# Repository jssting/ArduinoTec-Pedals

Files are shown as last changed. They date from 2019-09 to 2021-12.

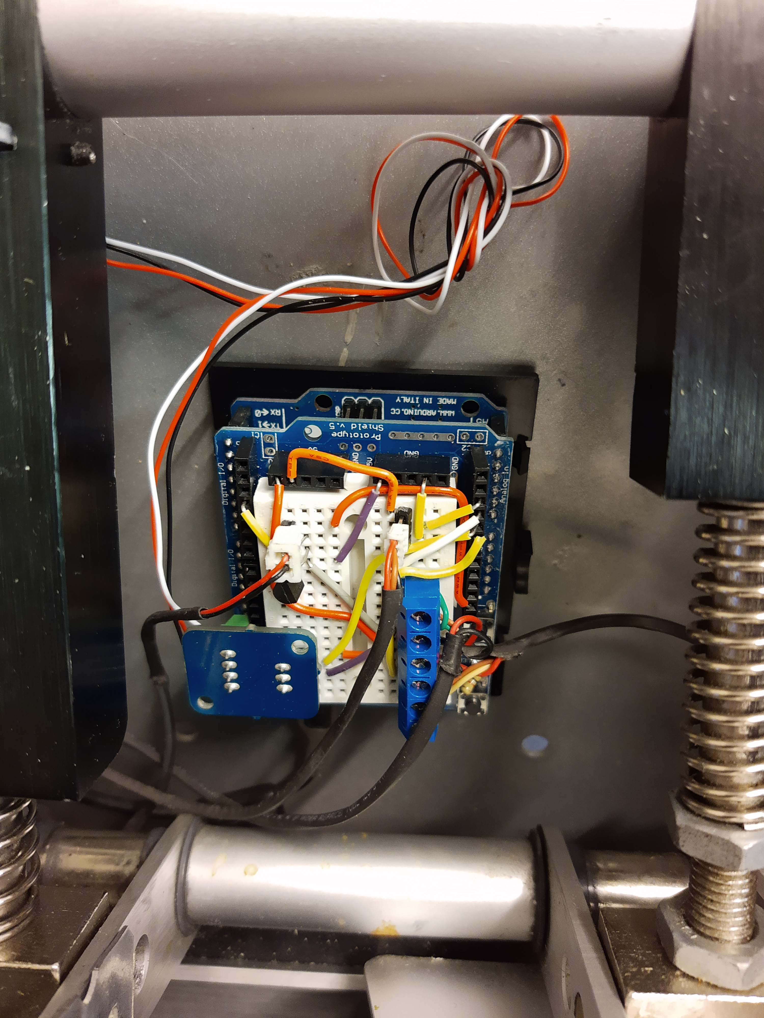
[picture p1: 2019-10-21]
IMG_20191006_190339238.jpg

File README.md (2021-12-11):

# ArduinoTec-Pedals
This project uses a Arduino Leonardo, Pro Micro or Teensy to replace the controller board of the Fanatec CSPV1. 
This is based on the https://github.com/MHeironimus/ArduinoJoystickLibrary library created by Matthew Heironimus
See the Circuit diagram for the wiring layout.

In addition to this you would need:

1. Arduino Leonardo (https://store.arduino.cc/usa/leonardo) or Pro Micro 5v 16mhz (https://www.sparkfun.com/products/12640)
2. a small breadboard or Arduino Shield (available on ebay and similar to the one shown at https://www.adafruit.com/product/51)to place it on if you don't want to solder the cables onto the board directly
3. Connectors if you want to be able to connect the load cells and HE sensors via a connector block
4. 1 load cell amp( existing fanatec one can be reused). I'used the Leo Bodnar LC Amplifier (http://www.leobodnar.com/shop/index.php?main_page=product_info&cPath=73&products_id=199). You can also re-use the existing one from the Fanatec Pedals(recommended), or use a hx711. The original LC amp is already correctly set, but the Leobodnar and HX711 will need to be configured in a half bridge mode, I added a 1k Ohm resistor across the input and GND(not 5V).
5. For the Vibration Motor I used a 2N3638 PNP Transistor rated to 25v to assist in driving the motor from the power source, controlled via the pwm on the Ardiuno. . 
6. I re-used the Fanatec Hall Effect sensors as mine were still in good working order. If you do want to use another sensor, ensure it is a linear sensor with Analog output that can sense the distance of the magnet/and field variation. Do not use arduino ones as they one sense on/off and not field variation. 
Connect the items as per the diagram, write the code to the Arduino, plug into the USB, calibrate via driver calibration screen, and you are ready to race.

Tuning notes:

1. The fixed position of the stock magnet may make it difficult to determine where to place the replacement Hall Effect sensor. Another magnet will confirm the HE sensor is working as expected. Depending on the sensor used it may help to rotate it 90 degrees.
2. When determining the location of the HE sensor it helps to use reusable adhesive (e.g. Blu-Tack:registered:) to temporarily affix it. Depending on sensor packaging it should be electrically isolated to avoid contact with the metal pedal. This could be done with cardboard or some other material.
3. Alternate magnet and HE sensor locations can be considered. For example: a magnet moved to the bottom of the pedal and HE sensor affixed to the frame. This would be similar to how the Thrustmaster T-LCM pedals work. Another approach would be to place magnet and HE sensor so they are inline at either end of the compression spring.

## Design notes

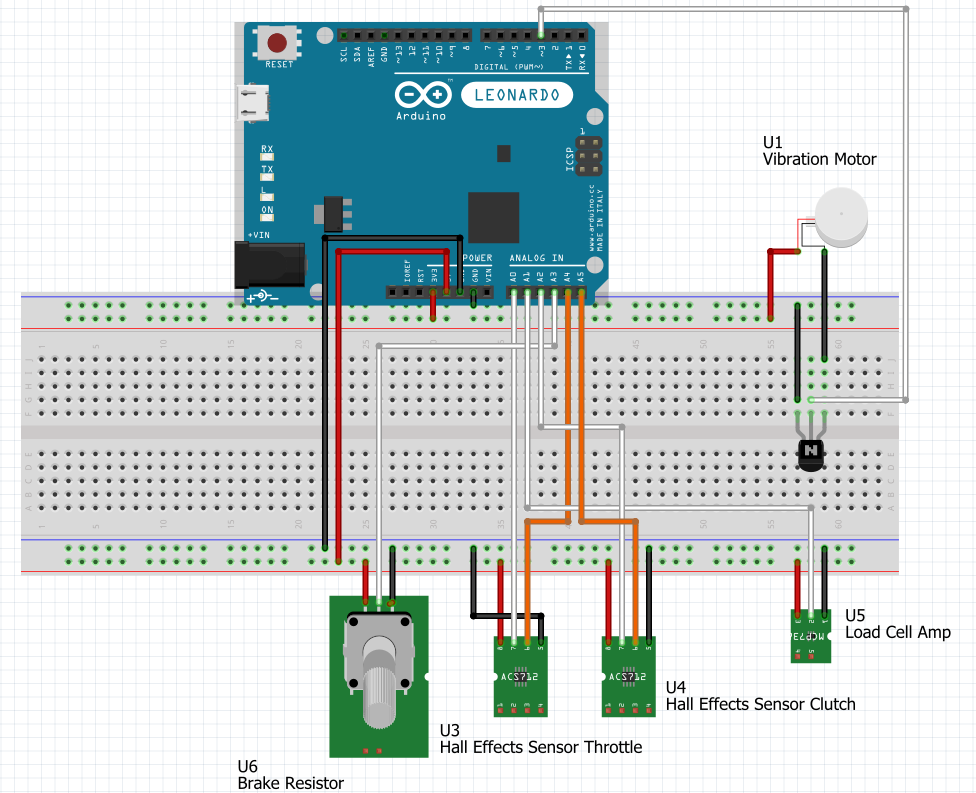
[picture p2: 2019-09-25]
Circuit Diagram.PNG

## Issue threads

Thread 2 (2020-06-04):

When flashed to Pro Micro, Connects then disconnects USB interface on pc

Djmeeg, 2020-06-04:
Hi, I flashed a Pro Micro with the sketch but when plugged into pc it just connects shows briefly then disconnects. This continues to happen. Do you know the correct wiring for pro micro ? Also I have 4 wires from the loadcell amp not just 3. Please advice would be great i would love to use this sketch.

jssting, 2020-06-04:
I am correctly assuming that you are using a 5v/16mhz Pro Micro)The wiring should be consistent, but make sure that you use A0-A3 for the brake, 1st line from each HE(Hall Effects) Sensor and the potentiometer (also you don't need to connect the orange lines from the HE sensors but if you do, connect then to A6, A7, A8 or A9 as per https://cdn.sparkfun.com/datasheets/Dev/Arduino/Boards/ProMicro16MHzv1.pdf) .
Which loadcell amp are you using , if you can include an picture or model number that would help.
Also, make sure:
- if you are using the fanatec loadcell, you only need to connect 3 of the lines, Red (5), Black(GND) and either green or Brown).

- If your loadcell amp uses analog output, make sure it is connected to an analog input on the arduino.
- If you are using the loadcell with SCK and DT (digital) outputs, I suggest looking at also including the HX711 Library (https://www.arduinolibraries.info/libraries/hx711-arduino-library) and using that, but it will need additional code as you need to then do some initial calibration.
- Your PWM pin for the brake vibration motor should then be either PIN 3, 5, 6, 9 or 10 (recommended) as those are the PWM pins on the Pro Micro, but given the Vib Motor expects 3.3v you may have to reduce the 5v to 3.3v (as Pro Micro only has 5v output) first using a resistive divider (see https://hackaday.com/2016/12/05/taking-it-to-another-level-making-3-3v-and-5v-logic-communicate-with-level-shifters/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,from%20an%20applied%205V%20input.) or refrain from using the Vibration motor, as 5v will burn it out quickly.

Also, something could be incorrectly wired, so I suggest if it is connecting and disconnecting, just remove the 5v from each input and see if this is still happening, if not then start adding them back one by one until you find the culprit, and make sure the transistor is correctly wired.

I currently use this in my pedal set and haven't has any issues.

Hope this is helpful

Djmeeg, 2020-06-07:
Hi, Thank you for taking the time to explain and help me. Its really appreciated. So rather than show you how I have it wired. I have made diagram of how I will wire it up. If you don’t mind taking a look and see what you think. Please any suggestions or alterations are welcome.

So I order the same resistor as on your original diagram and wired it the same. Or at least how I have it in my diagram.

What I was doing wrong is the vibration motor I just wired into the 5v so I ordered a step down to 3,3v which is also in the diagram.

Will I need to change any code ?  Also do you know what the brown wires are for ? Are they just signal cables also ?

Regards
Andy

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

jssting, 2020-06-08:
Hi Andy, the brown wires are also analog signal wires. Please attach your diagram and I am happy to have a look at it. As long as you are pushing the control via PWM then you should not need to change any code.

Djmeeg, 2020-06-08:
Hi, thanks again for getting back to me. I did attatch the diagram to the last email. Is there any other way I can send it ? I ve attached it again just let me know if you can’t see it.

Regards
Andy

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

jssting, 2020-06-08:
it is not showing up in the replies, can you send the image to my email address: jssting@hotmail.com?

jssting, 2020-06-18:
Code has been updated for dual precision inputs

Closed 2020-06-18.

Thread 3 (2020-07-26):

How connect the original load cell amplificator

ale8534, 2020-07-26:
Hello thank you for the code. Throttle and clutch are perfect. But I don't understand how to connect the fanatec load cell with arduino. In the diagram you have 4 cables coming out from the load cell ampli. But in the fanatec load cell ampli there are 4.
Can you help me to understand?

Thank you

Alessandro

jssting, 2020-07-28:
Hi Alessandro,
You should be able to use either of the two data lines (Orange and Brown) that are passed back from the load cell amplifier. The primary line is the Brown one, and the Yellow is added for precision.

________________________________
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

Closed 2021-12-06.

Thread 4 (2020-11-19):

Hi!

M0rta, 2020-11-19:

M0rta, 2020-11-19:
This is just a query and I hope maybe you can help me.
I am trying to connect a pressure regulator to my load cell, like the fanatec, based on hx711 and arduino, but I can't understand how everything is connected. Could you help me with this? It is not fanatec, but a homemade pedal board made from scratch.
It is already working and I can pass the code to you so that you can review it and modify it if you have some time. Thanks a lot!

jssting, 2020-11-19:
Happy to help where I can.
For the hx711, you will need to get the hx711 scale library. Also you will need to hook it up to a digital pin, as it uses a digital signal from the hx711 chip.
Please send me the code and I will have a look.
For better response you will also probably need to use pins with an attached interrupts, which will allow you to get a better response.

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

M0rta, 2020-11-19:
You are great!!!
ok, here the code. is working, im using it right now.

#include <HX711.h>
#include <Joystick.h>

#define LOADCELL_DOUT_PIN 0
#define LOADCELL_SCK_PIN 1
#define scale_factor -1250 // Do your calibration first. default -1000

HX711 brake;
float throttle_raw;
float throttle_raw_max = 512.0;
float brake_raw;
float brake_raw_max = 1023.0;
float clutch_raw;
float clutch_raw_max = 512.0;
float max_output_value = 1023;

Joystick_ Joystick(JOYSTICK_DEFAULT_REPORT_ID,
  JOYSTICK_TYPE_JOYSTICK, 12, 3,
  false, false, true, false, false, false,
  false, true, false, true, false);

int zAxis_ = 0;
int brake_ = 0;
int Throttle_ = 0;

void setup() {
    
  brake.begin(LOADCELL_DOUT_PIN, LOADCELL_SCK_PIN);
  //brake.tare(-100);
  brake.tare();
  brake.set_scale(scale_factor);

//  pinMode(A2, INPUT);           // set potentiometer pins to input
//  pinMode(A3, INPUT);

  Joystick.begin();
}
int16_t convertValue(float raw_reading, float max_reading) {
  if(raw_reading > max_reading) {
    return max_output_value;
  }
  float result = (max_output_value * (raw_reading / max_reading));
  if(result < 0.0) {
    int16_t zero = 0;
    return zero;
  }
  int16_t ret_value = (int16_t)result;
  return ret_value;
}

void loop() {

zAxis_ = analogRead(A3);                    // analog read potentiometer 1 set z axis
zAxis_ = map(zAxis_,0,512,0,1023);
Joystick.setZAxis(zAxis_);

Joystick.setBrake(convertValue(brake.get_units(), brake_raw_max));

Throttle_ = analogRead(A2);                   // analog read potentiometer 1 set Throttle axis
Throttle_ = map(Throttle_,0,512,0,1023);
Joystick.setThrottle(Throttle_);

Tnx!!!!!
I am absolutely new to arduino, just a hobbyist and a lover of racing sims.

jssting, 2020-11-19:
HI,
Can you tell what is not working? Also do you have some diagrams of how you have the loadcell into the hx711 and how it’s wired into the solution?

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

M0rta, 2020-11-19:
Hello mate.
Indeed, it works as I sent it without, visible, problems.
What I would like to do and I don't know how, is exactly what you did in your project.
Adding a potentiometer to regulate the load of the cell, and well ... adding vibration to the pedal as you did would be the best.
I understand that your job is to replace the original electronics of your fanatec pedalboard and I understand that you use electronic parts that the pedalboard brings, but I took the dare to ask you if it was possible to do the same without having any fanatec parts and without the need for plates additional for this to work. I know that the motor can move without problems, and without reading telemetry from the game, but I just don't know how to do it.
Sorry for the length of the message !!!
Thanks for your time.
Link of how I have the cell connected to the hx711 (the arduino is illustrative). wheatstone bridge
https://storage.googleapis.com/stateless-www-faranux-com/2018/01/a9932407-fudo2wcjbwjwj0o.large_.jpg

jssting, 2020-11-20:
Hi,
You can do it two ways, wire the potentiometer into the circuit (hard, given the digital inputs from the hx711), or do what I did , which is basically a bit of a hack, if you can call it that. Firstly I wanted to determine the total resistance that I would allow the potentiometer to have, which was 50% max on my end. I would basically read the resistance of the potentiometer (analog 0-1023)/2 (0-50%) and then determine that as a percentage of the pedal value and then take that percentage of the pedal travel.
You also may want to add in some deadzone to the pedal travel as the pedals can get of out sync reasonably quickly, or you can simply use the windows driver calibration tool.

I hope that helps somewhat.

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

M0rta, 2020-11-20:
My last question, and I hope to fulfill this.
Your circuit and code, are they based on some part of the original hardware of the fanatec pedalboard or do you simply replace the complete electronics with this?
I hope my next message is to tell you that everything works fine!

jssting, 2020-11-20:
I actually used the potentiometer from the original board, and connected that to the Arduino using gnd + analog pin , but did not use the loadcell amplifier from the original pedal set.

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

Closed 2021-12-06.

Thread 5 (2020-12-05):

big lag in steering wheel when i use the pedal

Guyllaume875, 2020-12-05:
thanks for this share really helpful. I was sad to just put my fanatec v2 in the trash.
first time using arduino board and no coding experience ( big time learning for me ) !!

but  i was able to put all together, but in the first complete test (iracing) the steering wheel have big lag and it's undriveable.

did you have any idea on what happen?

thrustmaster TX steering wheel, the arduino have it's own usb plug

Second issue  in assetto corsa the brake signal seems to low the be recognize by the game

Closed 2020-12-06.

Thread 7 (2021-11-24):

Question on hall effect sensor options

john-, 2021-11-24:
This library looks excellent and I know I will be using it one way or the other.

The documentation indicates the ACS712 as an option for hall effect sensor.  Do you have reference to a board that has that IC and the supporting circuitry that can be mounted to the pedals?  This would replace the existing sensor board.

If not can the ACS712 IC be used to replace the existing hall effect IC on the stock pedal sensor boards?

jssting, 2021-11-24:
Hi John,
I don't have a specific circuit, I merely connected the sensor inline to the Arduino as it takes care of the power delivery and noise management. I was thinking of adding emf shielding, but never got that far

________________________________
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

jssting, 2021-11-24:
The existing one provided by Fanatec usually works fine, but that is a surface mount so you will need to find a similar chip with the same pinout

________________________________
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

john-, 2021-11-24:
> Hi John, I don't have a specific circuit, I merely connected the sensor inline to the Arduino as it takes care of the power delivery and noise management. I was thinking of adding emf shielding, but never got that far
> […](#)

Git it.  So the basic function will work with ACS712.  I will start with that.   Thanks!

john-, 2021-11-24:
Closing this as question was answered!

Closed 2021-11-24.

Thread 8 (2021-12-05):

My Experience with ACS732 HE Sensor

john-, 2021-12-05:
I am using a breakout board based on the ACS732 hall effect sensor ([SparkFun](https://www.sparkfun.com/products/14544)).  It has a gain pot and a pot to set the voltage reference.

With minimum gain I could not locate the sensor over the magnet like the stock hall effect sensor.  It is pretty far away but things generally work.   I modified the breakout board to reduce the gain to approximately 1 (previously was 2).  This got it closer to the magnet but still pretty far away.

Does this match anyone else's experience.   Do other hall effect sensors allow for placement like the stock one?

jssting, 2021-12-05:
Were you able to confirm operation with another magnet to unsure it was correctly detecting the position change of the magnet, if so , then I would try turning it 90degrees and trying to get to as close as possible to directly over the magnet, I used some cardboard to insulate and and bluetack to position the sensor and tested it that way, then drilled and threaded the hold in the side which aligned the sensor to the magnet

________________________________
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

john-, 2021-12-05:
The sensor operates it just needs to be pretty far away.   If close than it overloads.   I like the idea of bluetack and trying different orientations.

Thanks,

John

jssting, 2021-12-05:
Once you have determined the orientation, you could always 3d print a bracket to space it a proper distance away.. another person when an alternative route and relocated it to the bottom of the pedal with a bracket that would move the another magnet closer/ further similar to how the new Thrustmaster t-lcm pedals work

Get Outlook for Android<https://aka.ms/AAb9ysg>
________________________________
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

john-, 2021-12-05:
Moving another magnet like that is an idea I had not thought of!   With existing setup it seemed odd to turn that much pedal travel into such a small movement of the magnet.   Clearly it works but seems very fine tuned.

Thanks,
John

john-, 2021-12-06:
I hacked up a magnet and sensor like what you mentioned (magnet at bottom of pedal) and that seemed to give me much more control over things.   Thanks again for the ideas and the software!

Closed 2021-12-06.

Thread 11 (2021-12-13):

Question on Noise

john-, 2021-12-13:
I am using the Sparkfun ACS732 breakout board (Low Current model) as my clutch Hall Effect sensor.   I noticed in the output from ArduinoTec-Pedals and in Windows there are fluctuations in the pedal position.  It is pretty minor.   However, the Fanatec HE sensor does not exhibit this behavior (it is rock solid in the WIndows GUI).

I hooked them both up to an oscilloscope and see the ACS72 has signal that is 70-90mV peak to peak.   The Fanatec is 40-60mV peak to peak.

This probably explains the behavior.   What are others seeing?

john-, 2021-12-17:
I am closing this question as I will be implementing an alternate HE sensor.

john-, 2021-12-25:
Update: I switched to using a AS5600 Hall Effect sensor over the stock pedal magnet.  I am using I2C for communication but it supports analog voltage and PWM as well.  So far this sensor exhibits no noise and does not require any processing to add dead zone or reduce noise.

Closed 2021-12-17.

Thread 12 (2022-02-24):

Teensy compatibility?

mycowx, 2022-02-24:
Has this project been validated on a Teensy 3.1?   I am having problems compiling...

In file included from C:\Users\##\Documents\Arduino\libraries\ArduinoJoystickLibrary-master\src/Joystick.h:24:0,
                 from C:\Users\##\Downloads\ArduinoTec-Pedals-master\ArduinoTec-Pedals-master\ArduinoTec-Pedals\ArduinoTec-Pedals.ino:1:
C:\Users\##\Documents\Arduino\libraries\ArduinoJoystickLibrary-master\src/DynamicHID/DynamicHID.h:37:28: fatal error: PluggableUSB.h: No such file or directory
compilation terminated.
Error compiling for board Teensy 3.2 / 3.1.

mycowx, 2022-02-25:
Thanks, I see that now.  Your README.md mentions using a Teensy, but the HID library is for the 32u4 only.  I'll move to a pro micro instead.

john-, 2022-02-25:
I am not the author of the software and basing my knowledge on my understanding.  I happen to be using a Pro Micro (5V) successfully.

Also, be aware of this change that another person and myself had to make:

https://github.com/jssting/ArduinoTec-Pedals/issues/6

Closed 2022-02-25.

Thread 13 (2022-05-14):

Hi

TuTiSeK, 2022-05-14:
I have a problem with uploading the code to arduino, could you please help me? If you can, please contact me on FB "Jacob Johnson" without an avatar. Regards
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

john-, 2022-05-14:
It looks looks like you renamed the .ino file.   This leads me to believe that you copied that file by itself.  You can confirm if the confOptions.h file is in the same directory as the ino.

If this is the case clone/download the entire repository instead of copying individual files.

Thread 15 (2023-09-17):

Input noise

brgil96, 2023-09-17:
So Im using this on a Leonardo and everything works. However, the signal is very noisy i.e. if I hold a pedal in a position between 0 and 100% the input value fluctuates a lot. How can I solve the issue?
I probably have dirty power in this house in case that matters

jssting, 2023-09-18:
Your USB cable should already contain a EMI/RFI shield {ferrite choke), if not, then I suggest trying one that has a shield. you can also confirm that the pedal set is properly grounded (attaching a ground wire to the pedals and something that is grounded like the computer case. I haven't seen something like that before but there is many way to filter out noisy lines. Also make sure your sensors are as close to the pedals as possible to limit interference.

________________________________
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

jssting, 2023-09-19:
The Leonardo already has a host of capacitors inline and pullup resistors on the Leonardo board to smooth out the signal and voltages on the pins. Adding capacitor inline with the sensor will add a ‘delay’ in input as it will keep smoothing out the signal way after you have changes the pedal position i.e. pedal still readying 20% when you are at 0%. I suspect it is either a
noisy sensor or a noisy output on the Leonardo. To validate that it is the sensor I would put the sensor on a different pin on the Leonardo, also look for a Analog only pin if you have a sensor with analog output.

To validate the pin for noise I would use an analogue write loop (0-255 and back to 0) to the pin and put a multi-meter (with DC voltage selected) on it to see if it goes from 0v to 5v and back consistently.

In addition, I would also check if there are any other inputs that are causing noise.
Note: some of the “non original” Leonardo’s are known for being a bit noisy, to counter act this you could add a small delay in the loop 50-120ms to account for the noise, but you loose fidelity.

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

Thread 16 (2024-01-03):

Is it possible connect arduinoTec-Pedal to Fanatec wheel base directly?

mgs1992, 2024-01-03:
is there anyway could connect a diy pedal to wheel base directly?

jssting, 2024-01-03:
I would hazard a guess that it would not work as the wheelbase is expecting to talk to the fanatec firmware on the pedal controller board, so would probably not work.

Get Outlook for Android<https://aka.ms/AAb9ysg>
________________________________
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

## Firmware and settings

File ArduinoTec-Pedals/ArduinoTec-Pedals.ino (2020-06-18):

#include <Joystick.h>
#include "confOptions.h"
#define Throttle          A0
#define Brake             A1
#define Clutch            A2

#define Throttle_I2       A5 //second input line (brown wire)
#define Brake_I2          A6 //second input line (brown wire)
#define Clutch_I2         A8 //second input line (brown wire)

#define BrakeResistance   A3
#define VibrationMotor    3

Joystick_ Joystick(JOYSTICK_DEFAULT_REPORT_ID,
                   JOYSTICK_TYPE_MULTI_AXIS, 0, 0,
                   false, false, false, true, false, false,
                   false, true, false, true, false);

const int MaxRange = 1023;
const int MinRange = 0;

const int AxisMax = 1024;

int blBrk = 0;
int blThr = 0;
int blCth = 0;
int maxBrk = 0; //max value for Brake
int maxThr = 0; //max value for Throttle
int maxCth = 0; //max value for Clutch
bool aveBrkSet = false;
bool aveThrSet = false;
bool aveCthSet = false;

bool debug = false;
bool dbg_PrintThr = false;
bool dbg_PrintBrk = false;
bool dbg_PrintCTH = false;

void setup() {
  delay(2000); //set a delay for everything to settle
      
  debug = Enable_Debug;
  dbg_PrintThr = Debug_Thr;
  dbg_PrintBrk = Debug_Brk;
  dbg_PrintCTH = Debug_Cth;

  //setting ranges
  Joystick.setRxAxisRange(MinRange, MaxRange);
  Joystick.setThrottleRange(MinRange, MaxRange);
  Joystick.setBrakeRange(MinRange, MaxRange);

  Joystick.begin(true);

  // Setting Pin Modes
  pinMode(Throttle, INPUT); //Throttle  
  pinMode(Brake, INPUT); //Brake
  pinMode(Clutch, INPUT); //Clutch
  
  //Setting optional pins states
  if (use_Dual_Thr) pinMode(Throttle_I2, INPUT); //Throttle input 2
  if (use_Dual_Cl) pinMode(Clutch_I2, INPUT); //Clutch input 2
  if (use_Dual_Brk) pinMode(Brake_I2, INPUT); //Brake input 2
  
  pinMode(BrakeResistance, INPUT); //BrakeResistance;
  pinMode(VibrationMotor, OUTPUT); // Vibration Motor Control this is paired with a transistor to control the motor
  pinMode(13, OUTPUT); // LED output
  digitalWrite(VibrationMotor, HIGH); // set the pin as High, Low will result in the motor spinning

  // get the baseline registering values
  blBrk = get_baseline(Brake, 25);
  blThr = get_baseline(Throttle, 25);
  blCth = get_baseline(Clutch, 25);
}

void loop() {
  //reading the relevant values from the pedals
  int valThr = 0;
  int valBrk = 0;
  int valCth = 0;
  
  if (use_Dual_Thr) valThr = abs((analogRead(Throttle)+analogRead(Throttle_I2))/2);
  else valThr = analogRead(Throttle);
  
  if (use_Dual_Cl) valCth = abs((analogRead(Clutch)+analogRead(Clutch_I2))/2);
  else valCth = analogRead(Clutch);
  
  if (use_Dual_Brk) valBrk = abs((analogRead(Brake)+analogRead(Brake_I2))/2);
  else valBrk = analogRead(Brake);
  
  /* Original read statements
  int valThr = analogRead(Throttle);
  int valBrk = analogRead(Brake);
  int valCth = analogRead(Clutch); */
  
  int valRestBrk = analogRead(BrakeResistance);
  double pers = get_Persentage(BrakeResistance); //get the resistance persentage to apply against the brake pedal which then halved

  //All values below are normalised and converted to absolute to ensure a positive value
  int actCthVal = abs(valCth - blCth);//normalised clutch value 
  int actThrVal = abs(valThr - blThr);//normalised Throttle value
  int actBrkVal = abs(valBrk - blBrk);//normalised brake value
  int PersBrkVal = int(((valBrk - blBrk) * pers)) ; //normalised brake value with the resistance added

  // set/update the max value based on pedal progressions
  if (maxCth < actCthVal) maxCth = actCthVal;
  if (maxThr < actThrVal) maxThr = actThrVal;  
  if (maxBrk < actBrkVal) maxBrk = actBrkVal;

  if (debug) {
    if(dbg_PrintThr){      
      String values = "Throttle - Baseline: " + String(blThr) + ", Actual Value: " + String(valThr) + ", Normalised Value: " + String(actThrVal) + ", max value: " + String(maxThr);
      Serial.println(values);
      delay(100);}
 
    if(dbg_PrintBrk){
       String values = "Brakes - Baseline: " + String(blBrk) + ", Actual Value: " + String(valBrk) + ", Normalised Value: " + String(actBrkVal) + ", Normalised With Resistance:" + String(PersBrkVal) + ", Pers:" + String(pers) + ", Resistance: " + String(valRestBrk) + ", max value: " + String(maxBrk);
       Serial.println(values);
       delay(100);}
    
    if(dbg_PrintCTH){
      String values = "Clutch - Baseline: " + String(blCth) + ", Actual Value: " + String(valCth) + ", Normalised Value: " + String(actCthVal) + ", Max Value: " + String(maxCth);                      
      Serial.println(values);
      delay(100);}  
    Serial.println("");//create an empty line   
  }

  if (actBrkVal > (maxBrk * 0.80)) digitalWrite(VibrationMotor, LOW); //enable the motor to spin when the pedal reaches 80% of the pedal pressure
  else digitalWrite(VibrationMotor, HIGH); //stop the motor when it falls below 80%

  //Limit upperbound Noise
  if (actCthVal  > (maxCth - clutch_U_DZ)  ) {actCthVal  = (maxCth - clutch_U_DZ);}
  if (actThrVal  > (maxThr - throttle_U_DZ)) {actThrVal  = (maxThr - throttle_U_DZ);}
  if (PersBrkVal > (maxBrk - brake_U_DZ)   ) {PersBrkVal = (maxBrk - brake_U_DZ);}
 
  //set the values applying base deadzone
  if (valCth >0) 
  {
    if (actCthVal > clutch_L_DZ) Joystick.setRxAxis(actCthVal);
    else Joystick.setRxAxis(0);
  }
  if (valThr >0) 
  {
    if (actThrVal > throttle_L_DZ) Joystick.setThrottle(actThrVal);
    else Joystick.setThrottle(0);
  }
  if (valBrk >0) 
  {
    if (actBrkVal > brake_L_DZ) Joystick.setBrake(PersBrkVal);
    else Joystick.setBrake(0);
  }
}

int get_baseline(int pin, int count) { //get the pedal baseline
  int maxVal = 0;
  int newVal = 0;
  for (int i = 0; i < count; i++) {
    newVal = analogRead(pin);
    if (maxVal < newVal) maxVal = newVal;
  }
  return maxVal;
}

double get_Persentage(int pinToRead) {
  return (1 - (double(analogRead(pinToRead)) / AxisMax)); //1024 is the maximum
}

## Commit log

2020-06-18 Added dial precision inputs for brake, throttle and clutch
    Added dial precision inputs for brake, throttle and clutch to use both analog data lines from each sensor, which can be enabled per input via the ConfOptions File before you compile and upload to you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
2021-12-06 replace spaces in file names
    [ArduinoTec-Pedals.ino]
